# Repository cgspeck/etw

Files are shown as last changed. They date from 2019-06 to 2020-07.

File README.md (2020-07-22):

# Elevator Trim Wheel

I could not purchase a Saitek [Cessna Trim Wheel](https://www.amazon.com.au/Saitek-Flight-Cessna-Trim-Wheel/dp/B0058FAFI4) for love or money, so I thought I'd build one myself.

Features:

- appears as a Joystick/Game controller with a single axis;
- spin the wheel up or down to set axis value from -1000 through +1000;
- reset to 0 on button press;
- slide-switch to disable changing input;

These are used by flight-simmers to [trim their virtual aircraft](https://en.wikipedia.org/wiki/Trim_tab) so that they do not have to apply constant pressure to the flight yoke or joystick.

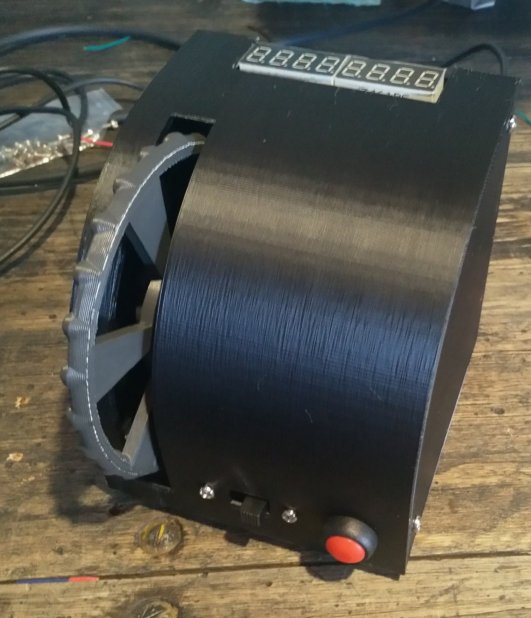
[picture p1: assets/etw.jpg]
Finished Trim Wheel


Required components:

- an [Arduino Leonardo](https://core-electronics.com.au/arduino-leonardo.html)
- [DF Robot SEN0230](https://core-electronics.com.au/incremental-photoelectric-rotary-encoder-400p-r.html) 400 P/R rotary encoder with bracket
- a 8 character 7-Segment LED display with a MAX7219 driver
- a monentary switch and DPST slide switch to suit
- various short jumper leads
- a handful of m3, m5 and m8 nuts, bolts and washers
- rough adhesive tape to enhance grip of the clamp

# 3D Prints

Use Openscad, your slicer and printer to render and then print one of each object in `scad/FauxtekElevatorTrim.scad`.

Use Openscad, your slicer and printer to render and then print the `scad/wheel-handle.scad`.

# Arduino Firmware

This project uses [Arduino-Makefile](https://github.com/sudar/Arduino-Makefile) to build, flash and test the Arduinos.

On Linux, install Arduino-Makefile then run `make upload` to flash your Arduino.

# Windows

Install the [Arduino IDE](https://www.arduino.cc/en/Guide/ArduinoLeonardoMicro#toc2) which installs the required drivers.

After installing the drivers and flashing the Arduino, it will appear as a game controller with a single axis and two buttons.

# FlightGear

Pre-made bindings are at `flightgear/cgspeck/Elevator-Trim-Wheel.xml`.

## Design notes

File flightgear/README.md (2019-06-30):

# FlightGear Support

Ensure the Arduino Leonardo drivers are installed, and copy the `cgspeck` folder to [`$FG_ROOT/Input/Joysticks`](http://wiki.flightgear.org/$FG_ROOT).

## Windows 10

On Windows you **must** install the Arduino Leonardo drivers, which are part of the [Arduino IDE](https://www.arduino.cc/en/Main/Software) package.

There is a guide [here](https://www.arduino.cc/en/Guide/DriverInstallation) about installing the correct driver.

If you have more then one USB controller plugged in then you must tell Flightgear which configuration to use for which device.

See `joysticks.xml` for an example. This file goes into the `$FG_ROOT` folder.

`$FG_ROOT` tends to be `Program Files\FlightGear 2016.1.1\data\` on Windows systems.

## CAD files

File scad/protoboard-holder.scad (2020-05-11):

/* [Hidden] */
$fn=72;

ProtoBoardHolder(136, 76);

module ProtoBoardHolder(
    dx,
    dy,
    frame_width=2,
    frame_height=6,
    fixing_tab_location="inside", // [none, inside, outside]
    tab_count=1,
    tab_hole_diameter=3, // Defaults are based on a #4 screw
    tab_head_diameter=6,
    tab_height=1.2,
    mount_hole_diameter=2.5, // Defaults are based on a #4 screw
    mount_post_diameter=2.8,
    mount_post_height=2.2,
    mount_1_type="hole", // [hole, post]
    mount_2_type="hole",
    mount_3_type="hole",
    mount_4_type="hole",
    pillar_height=3,
    with_support=true,
    board_y=20,
    board_y_clearance=2,
    support_hole_dia=2.5, // #4 screw
    only_support=false
) {
    inner_fn=32;
    mount_hole_rad=mount_hole_diameter / 2;
    mount_post_rad=mount_post_diameter / 2;

    pillar_radius=max([mount_hole_diameter, mount_post_diameter]);
    actual_pillar_height=frame_height + pillar_height;

    positions=[
        [0, dy, 0],
        [dx, dy, 0],
        [dx, 0, 0],
        [0, 0, 0]
    ];

    position_types=[
        [positions[0], mount_1_type],
        [positions[1], mount_2_type],
        [positions[2], mount_3_type],
        [positions[3], mount_4_type]
    ];

    half_frame_width = frame_width / 2;

    // EXT LIB
    module cylinder_outer(height,radius,center=false){
        fudge = 1/cos(180/inner_fn);
        cylinder(h=height,r=radius*fudge, center=center);
    }

    // Pillars first
    module Pillar() {
        cylinder(actual_pillar_height, pillar_radius, pillar_radius);
    }

    if (!only_support) {
        for(position_type=position_types) {
            if(position_type[1] == "hole") {
                difference() {
                    translate(position_type[0]) Pillar();
                    translate(position_type[0]) cylinder_outer(actual_pillar_height, mount_hole_rad);
                }
            } else {
                union() {
                    translate(position_type[0]) Pillar();
                    translate(position_type[0]) cylinder_outer(actual_pillar_height + mount_post_height, mount_post_rad);
                }
            }
        }
    }

    // Frame
    outer_rect_x_len = positions[1].x + frame_width;
    outer_rect_y_len = positions[1].y + frame_width;
    outer_rect_x_pos = positions[0].x - half_frame_width;
    outer_rect_y_pos = positions[3].y - half_frame_width;

    inner_rect_x_len = outer_rect_x_len - frame_width * 2;
    inner_rect_y_len = outer_rect_y_len - frame_width * 2;
    inner_rect_x_pos = outer_rect_x_pos + frame_width;
    inner_rect_y_pos = outer_rect_y_pos + frame_width;

    if (!only_support) {
        difference() {
            translate([outer_rect_x_pos, outer_rect_y_pos, 0]) cube([outer_rect_x_len, outer_rect_y_len, frame_height]);
            translate([inner_rect_x_pos, inner_rect_y_pos, 0]) cube([inner_rect_x_len, inner_rect_y_len, frame_height]);

            // holes through the frame where needed
            for(position_type=position_types) {
                if(position_type[1] == "hole") {
                    translate(position_type[0]) cylinder_outer(actual_pillar_height, mount_hole_rad);
                }
            }
        }
    }

    tab_hole_rad=tab_hole_diameter/2;
    tab_head_rad=tab_head_diameter/2;
    tab_x_len=tab_head_diameter * 2;
    tab_y_len=tab_x_len;

    tab_y_positions=[
        (positions[0].y / 3) * 1,
        (positions[0].y / 3) * 2,
    ];

    tab_x_positions=[
        positions[0].x,
        positions[1].x
    ];

    module FixingTab() {
        difference() {
            cube([tab_x_len, tab_y_len, tab_height]);
            translate([tab_x_len / 2, tab_y_len / 2, 0]) cylinder_outer(tab_hole_rad, tab_height);
        }
    }
    // tabs
    if (!only_support) {
        if (fixing_tab_location != "none") {
            for (i=[1:tab_count]) {
                tab_y_position = (positions[0].y / (tab_count + 1)) * i;
                if(fixing_tab_location == "inside") {
                    translate([frame_width / 2, tab_y_position - tab_y_len / 2, 0]) FixingTab();
                    translate([inner_rect_x_len - tab_x_len + frame_width /2, tab_y_position - tab_y_len / 2, 0]) FixingTab();
                } else  {
                    translate([-tab_x_len - frame_width / 2, tab_y_position - tab_y_len / 2, 0]) FixingTab();
                    translate([outer_rect_x_len - frame_width / 2, tab_y_position - tab_y_len / 2, 0]) FixingTab();
                }
            }
        }
    }

    if (with_support) {
        ShelfPoints = [
            [0, 0],
            [0, board_y + board_y_clearance],
            [board_y + board_y_clearance, board_y + board_y_clearance]
        ];
        hole_len = ShelfPoints[1][1] / 4;
        support_hole_rad = support_hole_dia / 2;
        difference() {

            union() {
                translate([
                    frame_width,
                    -(board_y - dy) / 2,
                    0]) {
                    rotate([90, 90, 90]) linear_extrude(tab_x_len) polygon(ShelfPoints);
                }

                translate([
                    dx - tab_x_len - frame_width,
                    -(board_y - dy) / 2,
                    0]) {
                    rotate([90, 90, 90]) linear_extrude(tab_x_len) polygon(ShelfPoints);
                }
            }
            for (i=[1:tab_count]) {
                tab_y_position = (positions[0].y / (tab_count + 1)) * i;
                translate([
                    tab_x_len / 2 + frame_width / 2,
                    tab_y_position,
                    -hole_len
                ]) cylinder_outer(hole_len, support_hole_rad);

                translate([
                    inner_rect_x_len - tab_x_len / 2 + frame_width /2,
                    tab_y_position,
                    -hole_len
                ]) cylinder_outer(hole_len, support_hole_rad);
            }
        }
    }
}

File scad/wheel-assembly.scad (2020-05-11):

include <MCAD/units.scad>

module WheelAssembly(cutout_mask=false) {
    fn=64;
    wheel_diameter = 108;
    encoder_diameter = 39;
    encoder_length = 36.5;
    encoder_wheel_distance = 5;
    wheel_radius  = wheel_diameter / 2;
    outdent_diameter = 8;
    wheel_clearance = 3;
    l_bracket_z = 3 * inch;
    l_bracket_x = 1.75 * inch;
    l_bracket_thickness = 2/32 * inch;

    encoder_x_pos = outdent_diameter + encoder_wheel_distance;


    module CylinderOuter(height,radius,center=false){
        fudge = 1/cos(180/fn);
        cylinder(h=height,r=radius*fudge, center=center);
    }

    rotate([0, 90, 0]) CylinderOuter(outdent_diameter, wheel_radius);

    rotate([0, 90, 0]) CylinderOuter(20, 3);

    translate([
        encoder_x_pos,
        0,
        0
    ]) rotate([0, 90, 0]) CylinderOuter(encoder_length, encoder_diameter / 2);

    translate([
        encoder_x_pos,
        -encoder_diameter / 2,
        -l_bracket_z + encoder_diameter / 2
    ]) cube([l_bracket_thickness, encoder_diameter, (l_bracket_z - encoder_diameter / 2)]);

    translate([
        encoder_x_pos,
        - encoder_diameter / 2,
        - l_bracket_z - l_bracket_thickness + encoder_diameter / 2
    ]) cube([l_bracket_x, encoder_diameter, l_bracket_thickness]);

    if (cutout_mask) translate([-wheel_clearance, 0, 0]) rotate([0, 90, 0]) CylinderOuter(outdent_diameter + 2 * wheel_clearance, wheel_radius + wheel_clearance);
}

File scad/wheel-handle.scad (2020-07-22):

use <MCAD/nuts_and_bolts.scad>
use <MCAD/regular_shapes.scad>

/* [ Basic ] */
WHEEL_DIAMETER=100;
HUB_DIAMETER=40;
HUB_THICKNESS=4;
ENCODER_SHAFT_DIAMETER=6;

/* [ Handle ] */
HANDLE_THICKNESS=6;
OUTDENT_COUNT=24;
OUTDENT_DIAMETER=8;

/* [ Spokes ] */
SPOKE_COUNT=3;
SPOKE_ANGLE_SPAN=60;

/* [ Bolt ] */
BOLT_DIAMETER=3;
BOLT_HEAD_DIAMETER=5.6;
NUT_WIDTH=5.4;
NUT_THICKNESS=1.7;
NUT_CLEARANCE=0.2;


/* [ Hidden ] */
BRIM_WIDTH=15;
CLEARANCE_TIGHT=0.2;
CLEARANCE_LOOSE=0.4;

HANDLE_OUTDENT_RADIUS=OUTDENT_DIAMETER / 2;
WHEEL_RADIUS=WHEEL_DIAMETER / 2;
HUB_RADIUS=HUB_DIAMETER / 2;
$fn=64;
ENCODER_SHAFT_RADIUS=ENCODER_SHAFT_DIAMETER/2 + CLEARANCE_LOOSE;
BOLT_RADIUS=BOLT_DIAMETER/2 + CLEARANCE_LOOSE;
BOLT_HEAD_RADIUS=BOLT_HEAD_DIAMETER/2;

BOLT_SHAFT_LENGTH=max(BOLT_HEAD_DIAMETER, NUT_WIDTH) * 1.5;
echo("Bolt shaft length: ", BOLT_SHAFT_LENGTH, "mm");
echo("Total object length: ", BOLT_SHAFT_LENGTH + HUB_THICKNESS, "mm");

TOTAL_D_CUTOUT_HEIGHT=BOLT_SHAFT_LENGTH+HUB_THICKNESS;


module cylinder_outer(height,radius,fn) {
   fudge = 1/cos(180/fn);
   cylinder(h=height,r=radius*fudge,$fn=fn);
}

module Handle() {
    // handle
    translate([0,0,HANDLE_THICKNESS/2]) torus2(WHEEL_RADIUS, HANDLE_THICKNESS/2);
    // outdents
    outdent_degrees = 360 / OUTDENT_COUNT;
    for(sector = [1 : OUTDENT_COUNT]) {
        angle = outdent_degrees * sector;
        x_pos = WHEEL_RADIUS * sin(angle);
        y_pos = WHEEL_RADIUS * cos(angle);
        translate([x_pos,y_pos,HANDLE_OUTDENT_RADIUS]){
            sphere(HANDLE_OUTDENT_RADIUS, center=true);
        }
    }
}

module HandleBrim() {
    _fn=72*4;
    // handle
    translate([0,0,HANDLE_THICKNESS/2]) difference() {
        cylinder_outer(0.3, WHEEL_RADIUS + BRIM_WIDTH, _fn);
        cylinder_outer(0.3, WHEEL_RADIUS - BRIM_WIDTH, _fn);
    }
}

module Spokes() {
    // spokes
    spoke_angle_half_span=SPOKE_ANGLE_SPAN/2;
    spoke_degrees = 360 / SPOKE_COUNT;
    for(sector = [1 : SPOKE_COUNT]) {
        angle_mid = spoke_degrees * sector;
        angle_min = angle_mid - spoke_angle_half_span;
        angle_max = angle_mid + spoke_angle_half_span;

        angle_q1 = angle_min + (spoke_angle_half_span * .5);
        angle_q3 = angle_mid + (spoke_angle_half_span * .5);
        // points near handle bar
        x1_pos = WHEEL_RADIUS * sin(angle_min);
        y1_pos = WHEEL_RADIUS * cos(angle_min);
        x2_pos = WHEEL_RADIUS * sin(angle_q1);
        y2_pos = WHEEL_RADIUS * cos(angle_q1);
        x3_pos = WHEEL_RADIUS * sin(angle_mid);
        y3_pos = WHEEL_RADIUS * cos(angle_mid);
        x4_pos = WHEEL_RADIUS * sin(angle_q3);
        y4_pos = WHEEL_RADIUS * cos(angle_q3);
        x5_pos = WHEEL_RADIUS * sin(angle_max);
        y5_pos = WHEEL_RADIUS * cos(angle_max);
        // points at hub
        x6_pos = HUB_RADIUS * sin(angle_max);
        y6_pos = HUB_RADIUS * cos(angle_max);
        x7_pos = HUB_RADIUS * sin(angle_min);
        y7_pos = HUB_RADIUS * cos(angle_min);

        translate([0,0,0]) linear_extrude(HUB_THICKNESS) polygon(points=[
            [x1_pos, y1_pos],
            [x2_pos, y2_pos],
            [x3_pos, y3_pos],
            [x4_pos, y4_pos],
            [x5_pos, y5_pos],
            [x6_pos, y6_pos],
            [x7_pos, y7_pos],
        ]);
    }
}


// hub
module _Shaft() {
    cylinder_outer(TOTAL_D_CUTOUT_HEIGHT, ENCODER_SHAFT_RADIUS, 64);
}

module Hub(push_fit=true, use_nyloc=false) {
    m3_nyloc_nut_thicknes=4.00;
    m3_nut_thickness=2.4;
    actual_m3_nut_thickness=use_nyloc ? m3_nyloc_nut_thicknes : m3_nut_thickness;
    nut_z_scale=actual_m3_nut_thickness/m3_nut_thickness;

    // HUB
    difference() {
        cylinder_outer(HUB_THICKNESS, HUB_RADIUS, $fn);
        //D cutout
        _Shaft();
    }

    // BOLT SHAFT
    BOLT_SHAFT_RADIUS=ENCODER_SHAFT_RADIUS + 3 * actual_m3_nut_thickness;

    echo("Bolt shaft radius:", BOLT_SHAFT_RADIUS, " mm");

    difference() {
        translate([0, 0, HUB_THICKNESS]) difference() {
            cylinder_outer(BOLT_SHAFT_LENGTH, BOLT_SHAFT_RADIUS, $fn);

            if (!push_fit) {
                // bolt hole
                translate([1, 0, BOLT_SHAFT_LENGTH / 2]) rotate([0, 90, 0]) cylinder_outer(BOLT_SHAFT_RADIUS, BOLT_RADIUS, $fn);
                // nut holes
                translate([ENCODER_SHAFT_RADIUS, 0, BOLT_SHAFT_LENGTH / 2]) rotate([0, 90, 0]) scale([1, 1, nut_z_scale]) nutHole(3);
                translate([0.1, 0, BOLT_SHAFT_LENGTH / 2]) rotate([0, 90, 0]) scale([1, 1, 1.4]) nutHole(3);
            }
        }
        _Shaft();
    }
}

Handle();
Spokes();
Hub();

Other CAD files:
scad/arduino.scad
scad/FauxtekElevatorTrim.scad
scad/_pins.scad

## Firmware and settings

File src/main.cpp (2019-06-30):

// hack to make VS Code work
#ifndef ARDUINO
  #define ARDUINO 189
#endif


#include <Arduino.h>
#undef round
#include <math.h>

#include <SPI.h>
#include <Joystick.h>
#include "debounce.h"
#include "display.h"

#define JOYSTICK_ENABLE
// #define TWO_AXIS

# define ENCODER_PULSES_PER_REV 400
# define JS_VAL_MIN 0
# define JS_VAL_MAX 1023

// how many times you have to spin the elevator wheel to go from min to max
# define JS_MIN_MAX_REVS 9

// ENCODER INPUT PINS
#define  A_PHASE 2
#define  B_PHASE 3

// RESET BUTTON
#define PIN_IN_RESET 11
unsigned int inputResetButtonHistory = 0;
unsigned long previousReset = 0;

// ARM (A)/DISARM (B) slide switch
#define PIN_IN_ARM 12
#define PIN_IN_DISARM 13
unsigned long previousModeChanged = 0;
bool armed = true;

// DISPLAY
#define LATCH_PIN 10

// JOYSTICK
#ifdef JOYSTICK_ENABLE
  Joystick_ Joystick(
    JOYSTICK_DEFAULT_REPORT_ID, 
    JOYSTICK_TYPE_JOYSTICK,
    3,
    0,
    true,
    #ifdef TWO_AXIS
      true,
    #else
      false,
    #endif
    false,
    false, false, false,
    false, false, false, false, false
  );
#endif

int JS_BUTTON_INTERVAL = 500;

int JS_MIDPOINT = round((JS_VAL_MIN + (float)JS_VAL_MAX) / 2);
int JS_AXIS_VAL;

volatile int ENCODER_VAL;
int PREVIOUS_ENCODER_VAL;
int ENCODER_AXIS_STEP;
int ENCODER_MIN_VAL;
int ENCODER_MAX_VAL;

void processPulse() {
  // stuff that figures out direction and increments or decrements the counter
  char i;
  i = digitalRead(B_PHASE);
  if (i == 1 && ENCODER_VAL < ENCODER_MAX_VAL) {
    // CCW
    ENCODER_VAL += 1;
  } else if (ENCODER_VAL > ENCODER_MIN_VAL) {
    // CW
    ENCODER_VAL -= 1;
  }
}

int scaledVal;

void updateScaledValues() {
  scaledVal = map(JS_AXIS_VAL, JS_VAL_MIN, JS_VAL_MAX, -100, 100);
}

void resetVals() {
  JS_AXIS_VAL = JS_MIDPOINT;
  ENCODER_VAL = 0;
  PREVIOUS_ENCODER_VAL = 0;
  #ifdef JOYSTICK_ENABLE
    Joystick.setXAxis(JS_AXIS_VAL);
    #ifdef TWO_AXIS
      Joystick.setYAxis(PREVIOUS_ENCODER_VAL);
    #endif
  #endif
  updateScaledValues();
}

void setup() {
  int jsRange = JS_VAL_MAX + abs(JS_VAL_MIN);

  // 444
  ENCODER_AXIS_STEP = ENCODER_PULSES_PER_REV / (jsRange/JS_MIN_MAX_REVS);
  // 18000
  ENCODER_MAX_VAL = (((float)JS_MIN_MAX_REVS / 2) * ENCODER_PULSES_PER_REV);
  // -18000
  ENCODER_MIN_VAL = ENCODER_MAX_VAL * -1;
  resetVals();
  pinMode(PIN_IN_RESET, INPUT_PULLUP);
  pinMode(PIN_IN_ARM, INPUT_PULLUP);
  pinMode(PIN_IN_DISARM, INPUT_PULLUP);
  armed = !digitalRead(PIN_IN_ARM); // logic flipped!
  attachInterrupt(digitalPinToInterrupt(PIN_IN_RESET), resetVals, RISING);
  pinMode(A_PHASE, INPUT);
  pinMode(B_PHASE, INPUT);
  attachInterrupt(digitalPinToInterrupt(A_PHASE), processPulse, RISING);

  #ifdef JOYSTICK_ENABLE
    Joystick.begin();
    Joystick.setXAxisRange(JS_VAL_MIN, JS_VAL_MAX);
    #ifdef TWO_AXIS
      Joystick.setYAxisRange(ENCODER_MIN_VAL, ENCODER_MAX_VAL);
    #endif
    Joystick.pressButton(armed ? 0 : 1);
  #else
    Serial.begin(9600);
  #endif

  pinMode(LATCH_PIN,OUTPUT);
  SPI.setBitOrder(MSBFIRST);
  SPI.begin();
  setupDisplay(LATCH_PIN);
}

void loop() {

  if (ENCODER_VAL != PREVIOUS_ENCODER_VAL) {
    if (ENCODER_VAL == ENCODER_MAX_VAL || ENCODER_VAL == ENCODER_MIN_VAL) {
      JS_AXIS_VAL = (ENCODER_VAL == ENCODER_MAX_VAL) ? JS_VAL_MAX : JS_VAL_MIN;
      noInterrupts();
      PREVIOUS_ENCODER_VAL = ENCODER_VAL;
      interrupts();
      updateScaledValues();
   } else if (abs(ENCODER_VAL - PREVIOUS_ENCODER_VAL) >= ENCODER_AXIS_STEP) {
      noInterrupts();
      // reset JS_AXIS_VAL
      JS_AXIS_VAL = map(
        ENCODER_VAL,
        ENCODER_MIN_VAL,
        ENCODER_MAX_VAL,
        JS_VAL_MIN,
        JS_VAL_MAX
      );
      PREVIOUS_ENCODER_VAL = ENCODER_VAL;
      interrupts();
      updateScaledValues();
    }
  }

  updateButton(&inputResetButtonHistory, PIN_IN_RESET);

  unsigned long currentMillis = millis();

  if (isButtonPressed(&inputResetButtonHistory)) {
    /* Reset button has just been released.
      
      Names are confusing, logic is flipped because of internal pull up resistor
    */
    #ifndef JOYSTICK_ENABLE
      Serial.println("************************** RESET **************************");
    #endif
    resetVals();
    previousReset = currentMillis;
    Joystick.pressButton(2);
  } else if ((unsigned long)(currentMillis - previousReset) > JS_BUTTON_INTERVAL) {
    Joystick.releaseButton(2);
  }

  bool modeChanged = false;

  if (armed && !digitalRead(PIN_IN_DISARM)) {
    armed = false;
    modeChanged = true;
  } else if (!armed && !digitalRead(PIN_IN_ARM)) {
    armed = true;
    modeChanged = true;
  }

  if (modeChanged) {
    #ifndef JOYSTICK_ENABLE
      Serial.println("************************** MODE CHANGED **************************");
    #else
      Joystick.pressButton(armed ? 0 : 1);
    #endif
    previousModeChanged = currentMillis;
  } else if ((unsigned long)(currentMillis - previousModeChanged) > JS_BUTTON_INTERVAL)
  {
    #ifdef JOYSTICK_ENABLE
      Joystick.releaseButton(0);
      Joystick.releaseButton(1);
    #endif
  }

  #ifdef JOYSTICK_ENABLE
    if(armed) {
      Joystick.setXAxis(JS_AXIS_VAL);
      #ifdef TWO_AXIS
        Joystick.setYAxis(PREVIOUS_ENCODER_VAL);
      #endif
    }
  #else
    Serial.print("PREVIOUS ENCODER VAL: ");
    Serial.println(PREVIOUS_ENCODER_VAL);
    Serial.print("JS_AXIS_VAL: ");
    Serial.println(JS_AXIS_VAL);
    Serial.print("SCALED VAL: ");
    Serial.println(scaledVal);
    Serial.print("ARMED: ");
    Serial.println(armed);
  #endif
  showNumber(scaledVal, LATCH_PIN);
}

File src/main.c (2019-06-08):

#include <Joystick.h>
#include "LedControl.h"

# define ENCODER_PULSES_PER_REV 4000
# define JS_VAL_MIN 0
# define JS_VAL_MAX 1023
# define JS_MIN_MAX_REVS 9
// ENCODER INPUT PINS
#define  A_PHASE 2
#define  B_PHASE 3

// RESET BUTTON
#define PIN_IN_RESET 4

// DISPLAY

// display
LedControl lc1=LedControl(12,11,10,1); 

// JOYSTICK
Joystick_ Joystick(
  JOYSTICK_DEFAULT_REPORT_ID, 
  JOYSTICK_TYPE_JOYSTICK,
  0,
  0,
  true, true, false,
  false, false, false,
  false, false, false, false, false
);

int JS_MIDPOINT = (JS_VAL_MIN + JS_VAL_MAX) / 2;
int JS_RANGE;
int JS_AXIS_VAL;

const int transpositionFactor = 0 - JS_MIDPOINT;
const int transposedMin = JS_VAL_MIN - transpositionFactor;
const int transposedMax = JS_VAL_MAX - transpositionFactor;

volatile int ENCODER_VAL;
int PREVIOUS_ENCODER_VAL;
int ENCODER_AXIS_STEP;
int ENCODER_MIN_VAL;
int ENCODER_MAX_VAL;

void processPulse() {
  // stuff that figures out direction and increments or decrements the counter
  char i;
  i = digitalRead(B_PHASE);
  if (i == 1 && ENCODER_VAL < ENCODER_MAX_VAL) {
    // CCW
    ENCODER_VAL += 1;
  } else if (ENCODER_VAL > ENCODER_MIN_VAL) {
    // CW
    ENCODER_VAL += 1;
  }
}

void resetVals() {
  JS_AXIS_VAL = JS_MIDPOINT;
  ENCODER_VAL = 0;
  PREVIOUS_ENCODER_VAL = 0;
  Joystick.setXAxis(JS_AXIS_VAL);
  Joystick.setYAxis(PREVIOUS_ENCODER_VAL);
  updateDisplay();
}

void setup() {
  JS_RANGE = JS_VAL_MAX + abs(JS_VAL_MIN);
  ENCODER_AXIS_STEP = ENCODER_PULSES_PER_REV / (JS_RANGE/JS_MIN_MAX_REVS);
  ENCODER_MAX_VAL = ((JS_MIN_MAX_REVS / 2) * ENCODER_PULSES_PER_REV);
  ENCODER_MIN_VAL = ENCODER_MAX_VAL * -1;
  resetVals();
  pinMode(PIN_IN_RESET, INPUT_PULLUP);
  attachInterrupt(digitalPinToInterrupt(PIN_IN_RESET), resetVals, RISING);
  pinMode(A_PHASE, INPUT);
  pinMode(B_PHASE, INPUT);
  attachInterrupt(digitalPinToInterrupt(A_PHASE), processPulse, RISING);
  Joystick.begin();
  Joystick.setXAxisRange(JS_VAL_MIN, JS_VAL_MAX);
  Joystick.setYAxisRange(ENCODER_MIN_VAL, ENCODER_MAX_VAL);

  for(int index=0;index<lc1.getDeviceCount();index++) {
    lc1.shutdown(index,false);
    lc1.setIntensity(index, 8);
  }
}

void printNumber(int v) {  
    int ones;  
    int tens;  
    int hundreds; 

    boolean negative=false;

    if(v < -999 || v > 999)  
        return;  
    if(v<0) {  
        negative=true; 
        v=v*-1;  
    }
    ones=v%10;  
    v=v/10;  
    tens=v%10;  
    v=v/10; hundreds=v;  
    if(negative) {  
        //print character '-' in the leftmost column  
        lc1.setChar(0,3,'-',false);  } 
    else {
        //print a blank in the sign column  
        lc1.setChar(0,3,' ',false);  
    }  
    //Now print the number digit by digit 
    lc1.setDigit(0,2,(byte)hundreds,false);
    lc1.setDigit(0,1,(byte)tens,false); 
    lc1.setDigit(0,0,(byte)ones,false); 
}

void updateDisplay() {
  // transpose JS vals around 0
  int transposedVal = JS_AXIS_VAL - transpositionFactor;
  // now scale it
  int scaledVal = (transposedVal / transposedMax) * 100;
  printNumber(scaledVal);
}

void loop() {
  if (abs(ENCODER_VAL - PREVIOUS_ENCODER_VAL) >= ENCODER_AXIS_STEP) {
    noInterrupts();
    // increase/decrease axis val
    if (ENCODER_VAL > PREVIOUS_ENCODER_VAL) {
      JS_AXIS_VAL += 1;
    } else {
      JS_AXIS_VAL -= 1;
    }
    PREVIOUS_ENCODER_VAL = ENCODER_VAL;
    interrupts();
    Joystick.setXAxis(JS_AXIS_VAL);
    Joystick.setYAxis(PREVIOUS_ENCODER_VAL);
    updateDisplay();
  }
}

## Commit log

2019-06-08 Integrate Joystick (need to compile in Arduino IDE :-( )
2019-06-08 Integrate LED display
2019-06-08 Integrate a reset button
2019-06-08 Integrating SPI based number display
2019-06-09 Add reset feature and a diagnostic mode
    [main.cpp]
2019-06-09 Actually allow the encoder to go backwards
2019-06-09 Use map function to scale encoder vals to js vals
2019-06-09 Encoder actually has '400 pulses/round for each phase'
2019-06-09 Activate the joystick and clear some compiler errors
    [main.cpp]
2019-06-09 Fix compiler warning (which partially corrected brightness). Added decimals flag
    [display.cpp]
2019-06-28 Flip the axis (down is up etc)
    [main.cpp]
2019-06-28 Have a slide switch to arm/disarm the trim wheel
2019-06-28 Report when the reset button is pressed
2019-06-30 Revert "Flip the axis (down is up etc)"
    Upside down, upside down...
    This reverts commit 59042d1eaacb9353cd124673e911432fa294f9ee.
    [main.cpp]
2020-05-11 Add models for trim wheel housing
    [FauxtekElevatorTrim.scad, _pins.scad, arduino.scad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]
2020-05-13 Have cut outs on the clamp screw protector so you can hold it with a wrench
    [FauxtekElevatorTrim.scad]
2020-05-13 With tolerance here the nuts fall out
    [FauxtekElevatorTrim.scad]
2020-05-13 Add wheel handle for completelness
    [wheel-handle.scad]
2020-05-13 Add clearance to the sideway bolt hole
    [wheel-handle.scad]
2020-05-13 Add more clearance around centre D cutout
    [wheel-handle.scad]
2020-05-14 Using the 'D' cutout with a square nut didn't really work, use a round cutout with an embedded hex nut instead
    [wheel-handle.scad]
2020-05-14 Ooops. wheel was way over sized. Also, it seems push-fit will do.
    [wheel-handle.scad]
2020-07-22 Add a readme
    [wheel-handle.scad]
